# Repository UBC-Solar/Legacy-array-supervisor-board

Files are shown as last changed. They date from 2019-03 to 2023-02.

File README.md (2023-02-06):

# Array Supervisor Board

The Array Supervisor Board (ASB) was designed for Daybreak in the summer of 2019 during preparations for FSGP 2019. Unfortunately, the team couldn't get it working before the competition and scrapped it (indeed, the team did not end up bringing Daybreak to FSGP 2019 as it wasn't finished in time). The ASB was at that point deemed an unnecessary addition for Daybreak and was never troubleshooted further and installed. That said, it was a useful concept, and the concept has been pursued for UBC Solar's next car following Daybreak.

The board was designed to be capable of measuring several voltages, currents and temperatures for the solar array, as well as controlling 3 relays to individually switch the two MPPTs on and off the high voltage bus. It is based on an STM32 Nucleo board and a TLV2556 ADC.

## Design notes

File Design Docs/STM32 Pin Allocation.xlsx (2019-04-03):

CN7 | Pin Name | Main Function | Default Alternate Function | Remap Alternate Function | Feature/Notes | ASB Function | CN10 | Pin Name | Main Function | Default Alternate Function | Remap Alternate Function | Feature/Notes | ASB Function
1 | PC10 | I/O | - | USART3_TX | 5V tolerant | I_OUT_1_OCD (GPIO) | 1 | PC9 | I/O | - | TIM3_CH4 | 5V tolerant | Power On LED (GPIO)
2 | PC11 | I/O | - | USART3_RX | 5V tolerant | I_IN_1_OCD (GPIO) | 2 | PC8 | I/O | - | TIM3_CH3 | 5V tolerant | Error LED (GPIO)
3 | PC12 | I/O | - | USART3_CK | 5V tolerant | I_OUT_2_OCD (GPIO) | 3 | PB8 | I/O | TIM4_CH3 | I2C1_SCL / CANRX | 5V tolerant, not connected when SB46,SB52 off | NC
4 | PD2 | I/O | TIM3_ETR | - | 5V tolerant | I_IN_2_OCD (GPIO) | 4 | PC6 | I/O | - | TIM3_CH1 | 5V tolerant | Generic LED 1 (GPIO)
5 | VDD | Supply | - | - | - | NC | 5 | PB9 | I/O | TIM4_CH4 | I2C1_SDA / CANTX | 5V tolerant, not connected when SB46,SB52 off | NC
6 | E5V | - | - | - | External 5V supply | 5V In from Buck (POWER) | 6 | PC5 | I/O | ADC12_IN15 | - | - | Voltage Sense 1 (ADC)
7 | BOOT0 | BOOT0 | - | - | For STM Boot Up, default = 0 but can be jumper'd high | NC | 7 | AVDD | Supply | Analog Vref | - | Connected to VDD through SB57 | NC
8 | GND | GND | - | - | - | GND (POWER) | 8 | U5V | Supply | USB 5V | - | - | NC
9 | NC | - | - | - | - | NC | 9 | GND | GND | - | - | - | GND (POWER)
10 | NC | - | - | - | - | NC | 10 | NC | NC | - | - | - | NC
11 | NC | - | - | - | - | NC | 11 | PA5 | I/O | SPI1_SCK / ADC12_IN5 | - | Connected to LD2 LED on nucleo board | Ext_ADC_SCK (SPI)
12 | IOREF | 3V3 Vref | - | - | Connected to 3V3 | NC | 12 | PA12 | I/O | USART1_RTS / CANTX / USBDP / TIM1_ETR | - | 5V tolerant | CANTX (CAN)
13 | PA13 | JTMS/SWDIO (JTAG) | - | I/O | 5V tolerant | JTAG (NC) | 13 | PA6 | I/O | SPI1_MISO / ADC12_IN6 / TIM3_CH1 | TIM1_BKIN | - | Ext_ADC_MISO (SPI)
14 | RESET | NRST | - | - | Connected to B2 button on Nucleo for reseting the MCU | NC | 14 | PA11 | I/O | USART1_CTS / CANRX / USBDM / TIM1_CH4 | - | 5V tolerant | CANRX (CAN)
15 | PA14 | JTCK/SWCLK (JTAG) | - | I/O | 5V tolerant | JTAG (NC) | 15 | PA7 | I/O | SPI_MOSI / ADC12_IN7 / TIM3_CH2 | TIM1_CH1N | - | Ext_ADC_MOSI (SPI)
16 | 3V3 | External 3V3 | - | - | 3V3 output, 500mA max | 3V3 Out (POWER) | 16 | PB12 | I/O | SPI2_NSS / I2C2_SMBAI / USART3_CK / TIM1_BKIN | - | 5V tolerant | Relay Control 1 (GPIO)
17 | PA15 | JTDI (JTAG) | - | TIM2_CH1_ETR, I/O, SPI1_NSS | 5V tolerant | JTAG (NC) | 17 | PB6 | I/O | I2C1_SCL / TIM4_CH1 | USART1_TX | 5V tolerant | Ext_ADC_EOC (GPIO)
18 | 5V | External 5V | - | - | 5V output, 500mA max | 5V Out (POWER) | 18 | PB11 | I/O | I2C2_SDA / USART3_RX | TIM2_CH4 | 5V tolerant | Relay Control 2 (GPIO)
19 | GND | GND | - | - | - | GND (POWER) | 19 | PC7 | I/O | - | TIM3_CH2 | 5V tolerant | I_IN_3_OCD (GPIO)
20 | GND | GND | - | - | - | GND (POWER) | 20 | GND | GND | - | - | - | GND (POWER)
21 | PB7 | I/O | I2C1_SDA / TIM4_CH2 | USART1_RX | 5V tolerant | I_OUT_3_OCD (GPIO) | 21 | PA9 | I/O | USART1_TX / TIM1_CH2 | - | 5V tolerant | USART1_TX (NC)
22 | GND | GND | - | - | - | GND (POWER) | 22 | PB2 | PB2 / BOOT1 | - | - | 5V tolerant | Relay Control 3 (GPIO)
23 | PC13 | I/O | TAMPER-RTC (Real Time Clock) | - | Connected to B1 user button | NC | 23 | PA8 | I/O | USART1_CK / TIM1_CH1 / MCO | - | 5V tolerant | USART1_CK (NC)
24 | VIN | External VIN | - | - | Can take 7-12V | 12V In (POWER) | 24 | PB1 | I/O | ADC12_IN9 / TIM3_CH4 | TIM1_CH3N | - | Voltage Sense 2 (ADC)
25 | PC14 | I/O | OSC32_IN | - | Used for LSE (low speed external clock) | NC | 25 | PB10 | I/O | I2C2_SCL / USART3_TX | TIM2_CH3 | 5V tolerant
26 | NC | - | - | - | - | NC | 26 | PB15 | I/O | SPI2_MOSI / TIM1_CH3N | - | 5V tolerant
27 | PC15 | I/O | OSC32_OUT | - | Used for LSE (low speed external clock) | NC | 27 | PB4 | I/O | JNTRST (JTAG) | - | 5V tolerant | JTAG (NC)
28 | PA0 | I/O | WKUP / USART2_CTS / ADC12_IN0 / TIM2_CH1_ETR | - | - | NC | 28 | PB14 | I/O | SPI2_MISO / USART3_RTS / TIM1_CH2N | - | 5V tolerant
29 | PD0 | I/O | - | CANRX | 5V tolerant, used for HSE, 8MHz external clock | NC | 29 | PB5 | I/O | I2C1_SMBAI | TIM3_CH2 / SPI1_MOSI | -
30 | PA1 | I/O | USART2_RTS / ADC12_IN1 / TIM2_CH2 | - | - | Input Current Sense 1 (ADC) | 30 | PB13 | I/O | SPI2_SCK / USART3_CTS / TIM1_CH1N | - | 5V tolerant
31 | PD1 | I/O | - | CANTX | 5V tolerant, used for HSE, 8MHz external clock | NC | 31 | PB3 | JTDO (JTAG) | - | TIM2_CH2 / PB3 / TRACESWO/ SPI1_SCK | 5V tolerant | JTAG (NC)
32 | PA4 | I/O | SPI1_NSS / USART2_CK / ADC12_IN4 | - | - | Ext_ADC_NSS (SPI) | 32 | AGND | GND | Analog Ground | - | Connected to GND through SB60 | GND (POWER)
33 | VBAT | Supply, 3.3V | - | - | Backup supply for RTC and backup registers | NC | 33 | PA10 | I/O | USART1_RX / TIM1_CH3 | - | 5V tolerant | USART1_RX (NC)
34 | PB0 | I/O | ADC12_IN8 / TIM3_CH3 | TIM1_CH2N | - | Input Current Sense 2 (ADC) | 34 | PC4 | I/O | ADC12_IN14 | - | - | Voltage Sense 3 (ADC)
35 | PC2 | I/O | ADC12_IN12 | - | - | Output Current Sense 1 (ADC) | 35 | PA2 | I/O | USART2_TX / ADC12_IN2 / TIM2_CH3 | - | Used for ST-LINK MCU | NC
36 | PC1 | I/O | ADC12_IN11 | - | - | Input Current Sense 3 (ADC) | 36 | NC | NC | - | - | - | NC
37 | PC3 | I/O | ADC12_IN13 | - | - | Output Current Sense 2 (ADC) | 37 | PA3 | I/O | USART2_RX / ADC12_IN3 / TIM2_CH4 | - | Used for ST-LINK MCU | NC
38 | PC0 | I/O | ADC12_IN10 | - | - | Output Current Sense 3 (ADC) | 38 | NC | NC | - | - | - | NC

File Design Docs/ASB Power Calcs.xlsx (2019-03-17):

12V Supply | Max Current Draw (mA) | 3.3V Supply | Max Current Draw (mA) | 5V Supply | Max Current Draw (mA)
STM MCU | 250 | Current Sensor x 6 | 150 | CAN Transceiver
Voltage Sense Op Amp x 3 | 12 | External ADC | 2.5
Temperature Sensor x 12 | 1
Gigavac contactor | 170
Omron Relay x 2 | 200

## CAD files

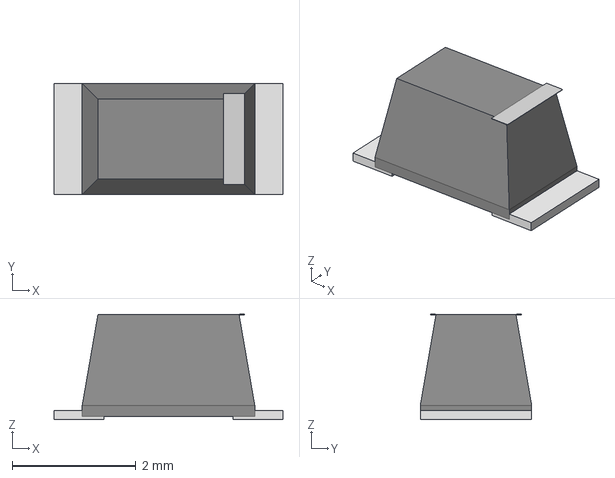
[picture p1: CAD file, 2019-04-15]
3D Models/CGRKM.step
3.71 x 1.80 x 1.71 mm

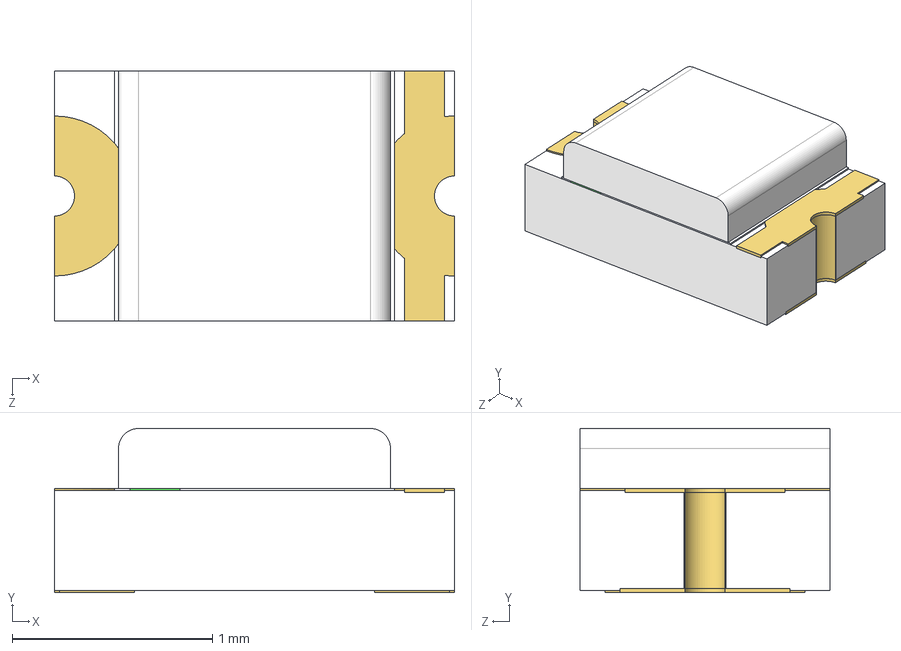
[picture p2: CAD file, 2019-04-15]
3D Models/L0805.step
2.00 x 0.82 x 1.25 mm

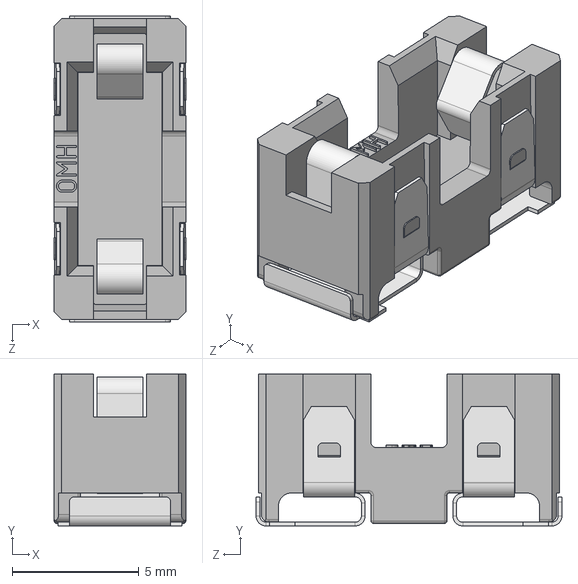
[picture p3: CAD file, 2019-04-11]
3D Models/FUSE HLDR CARTRIDGE 125V 5A SMD.STEP
5.20 x 6.00 x 12.1 mm

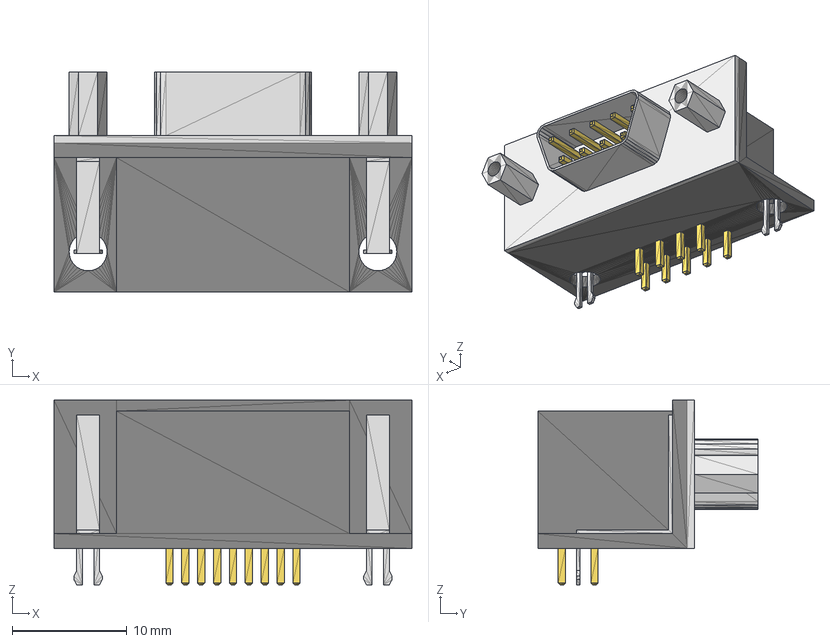
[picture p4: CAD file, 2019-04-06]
3D Models/D9 Connector.step
31.2 x 19.2 x 16.1 mm

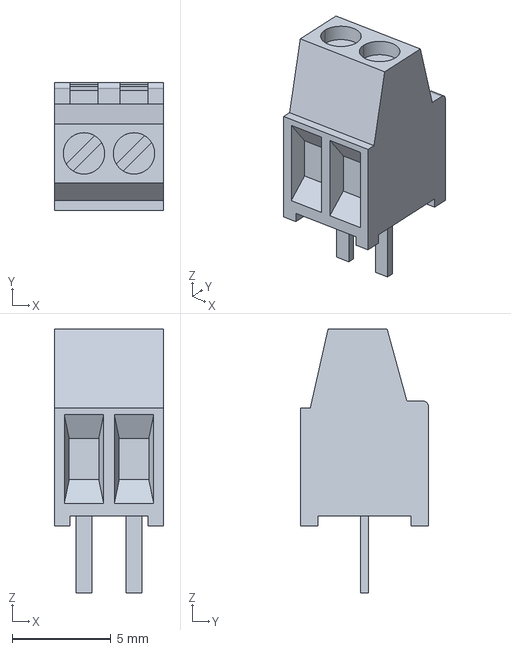
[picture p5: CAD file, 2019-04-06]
3D Models/TD Connectivity 28234-2.stp
5.54 x 6.50 x 13.4 mm

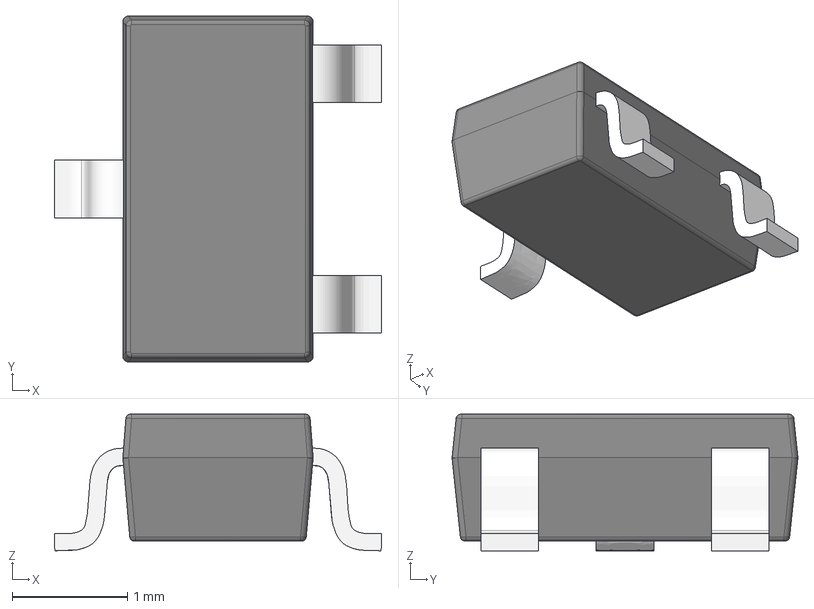
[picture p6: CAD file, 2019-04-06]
3D Models/MOSFET DMG6968U SOT23-3.stp
2.84 x 3.00 x 1.18 mm

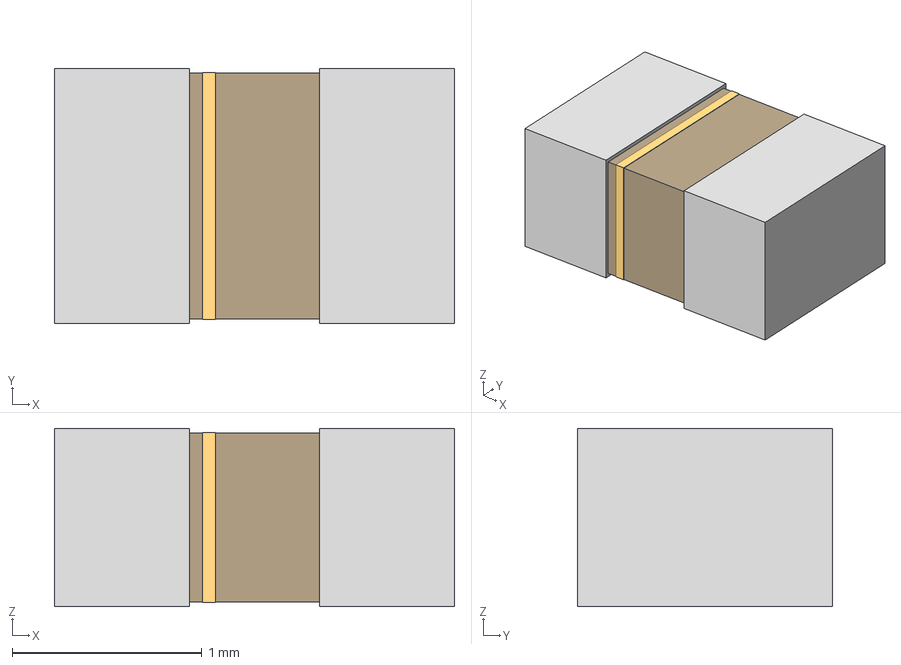
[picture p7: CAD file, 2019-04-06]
3D Models/CAP_0805C-L.step
2.11 x 1.35 x 0.94 mm

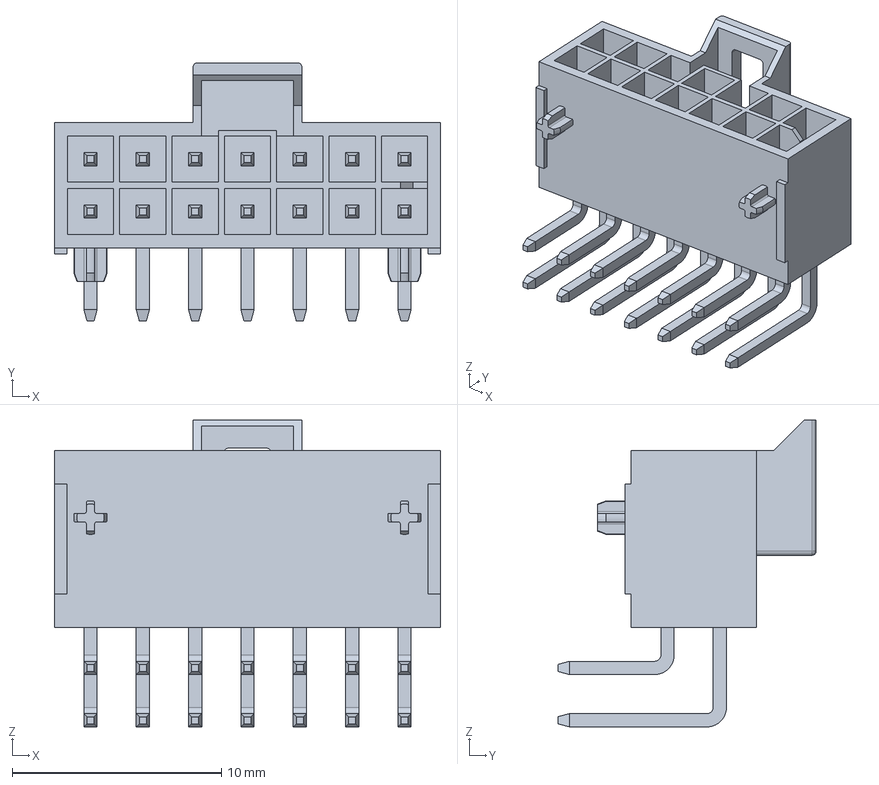
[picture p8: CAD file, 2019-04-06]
3D Models/MOLEX 105314 11 14 CON.stp
18.4 x 12.3 x 14.7 mm

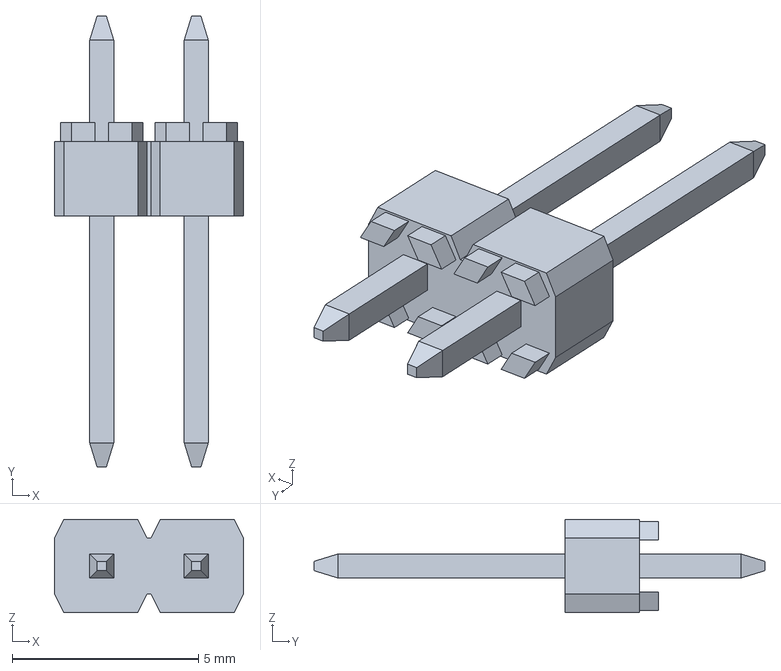
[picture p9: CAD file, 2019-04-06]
3D Models/Molex 901200762.stp
5.08 x 12.1 x 2.50 mm

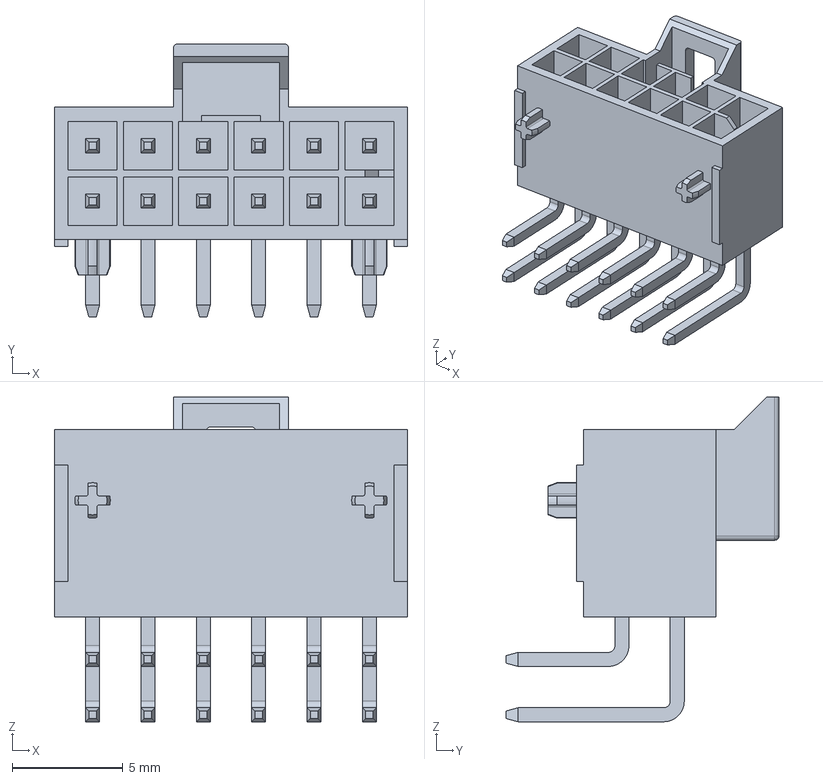
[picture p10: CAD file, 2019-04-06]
3D Models/MOLEX 105314 11 12 CON.stp
15.9 x 12.3 x 14.7 mm

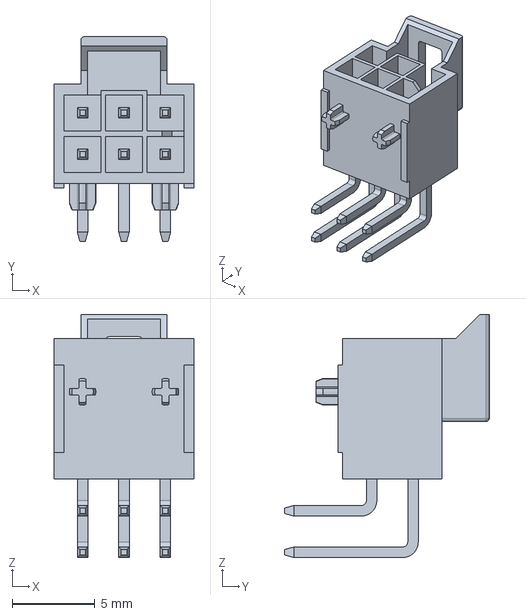
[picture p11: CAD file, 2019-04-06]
3D Models/MOLEX 105314 11 06 CON.stp
8.44 x 12.3 x 14.7 mm

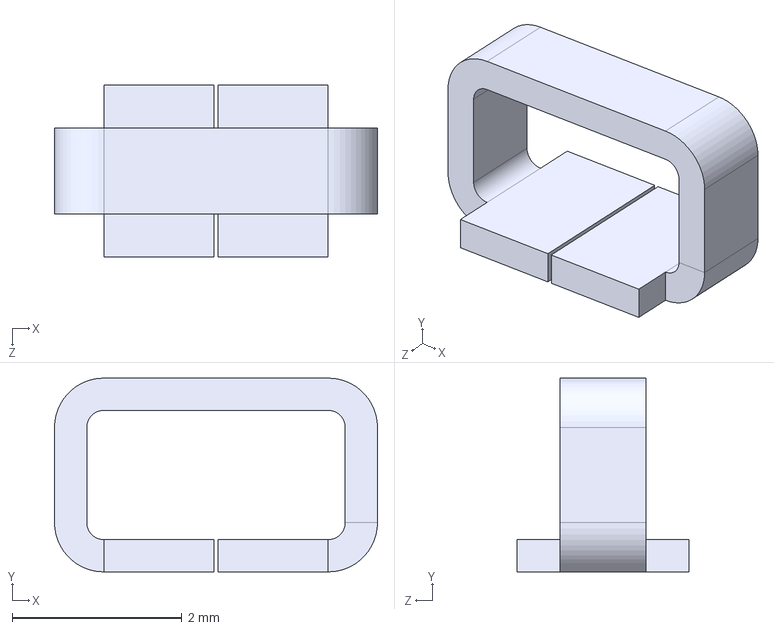
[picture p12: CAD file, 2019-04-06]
3D Models/5019 KEYSTONE SMT TEST POINT.STEP
3.81 x 2.29 x 2.03 mm

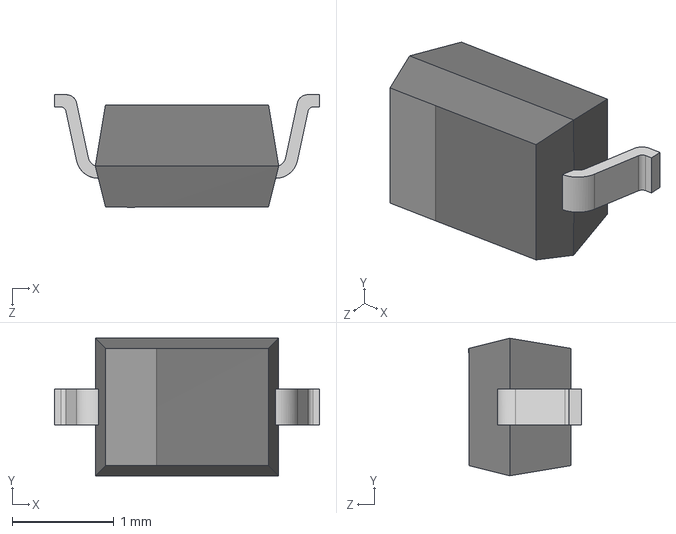
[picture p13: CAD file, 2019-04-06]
3D Models/SOD-323.STEP
2.60 x 1.35 x 1.10 mm

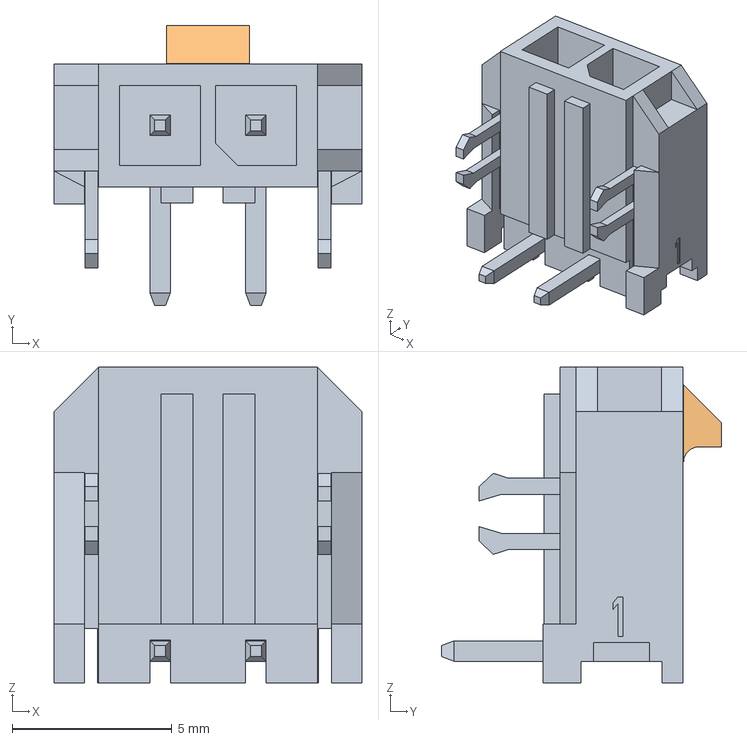
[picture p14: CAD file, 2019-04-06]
3D Models/Right Angle Header 436500205.stp
9.65 x 8.79 x 9.90 mm

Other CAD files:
3D Models/CAP_0805C-M.step
3D Models/C0805.step
3D Models/ESQ-119-24-T-D.stp
3D Models/SOIC08 narrow.stp
3D Models/1053141106.stp
3D Models/1053141208.stp
3D Models/705530001.stp
3D Models/901200763.stp
3D Models/CAPC-0805-T0.95-BN.stp
3D Models/CAPC-0805-T1.35-BN.stp
3D Models/RESC-0805.stp

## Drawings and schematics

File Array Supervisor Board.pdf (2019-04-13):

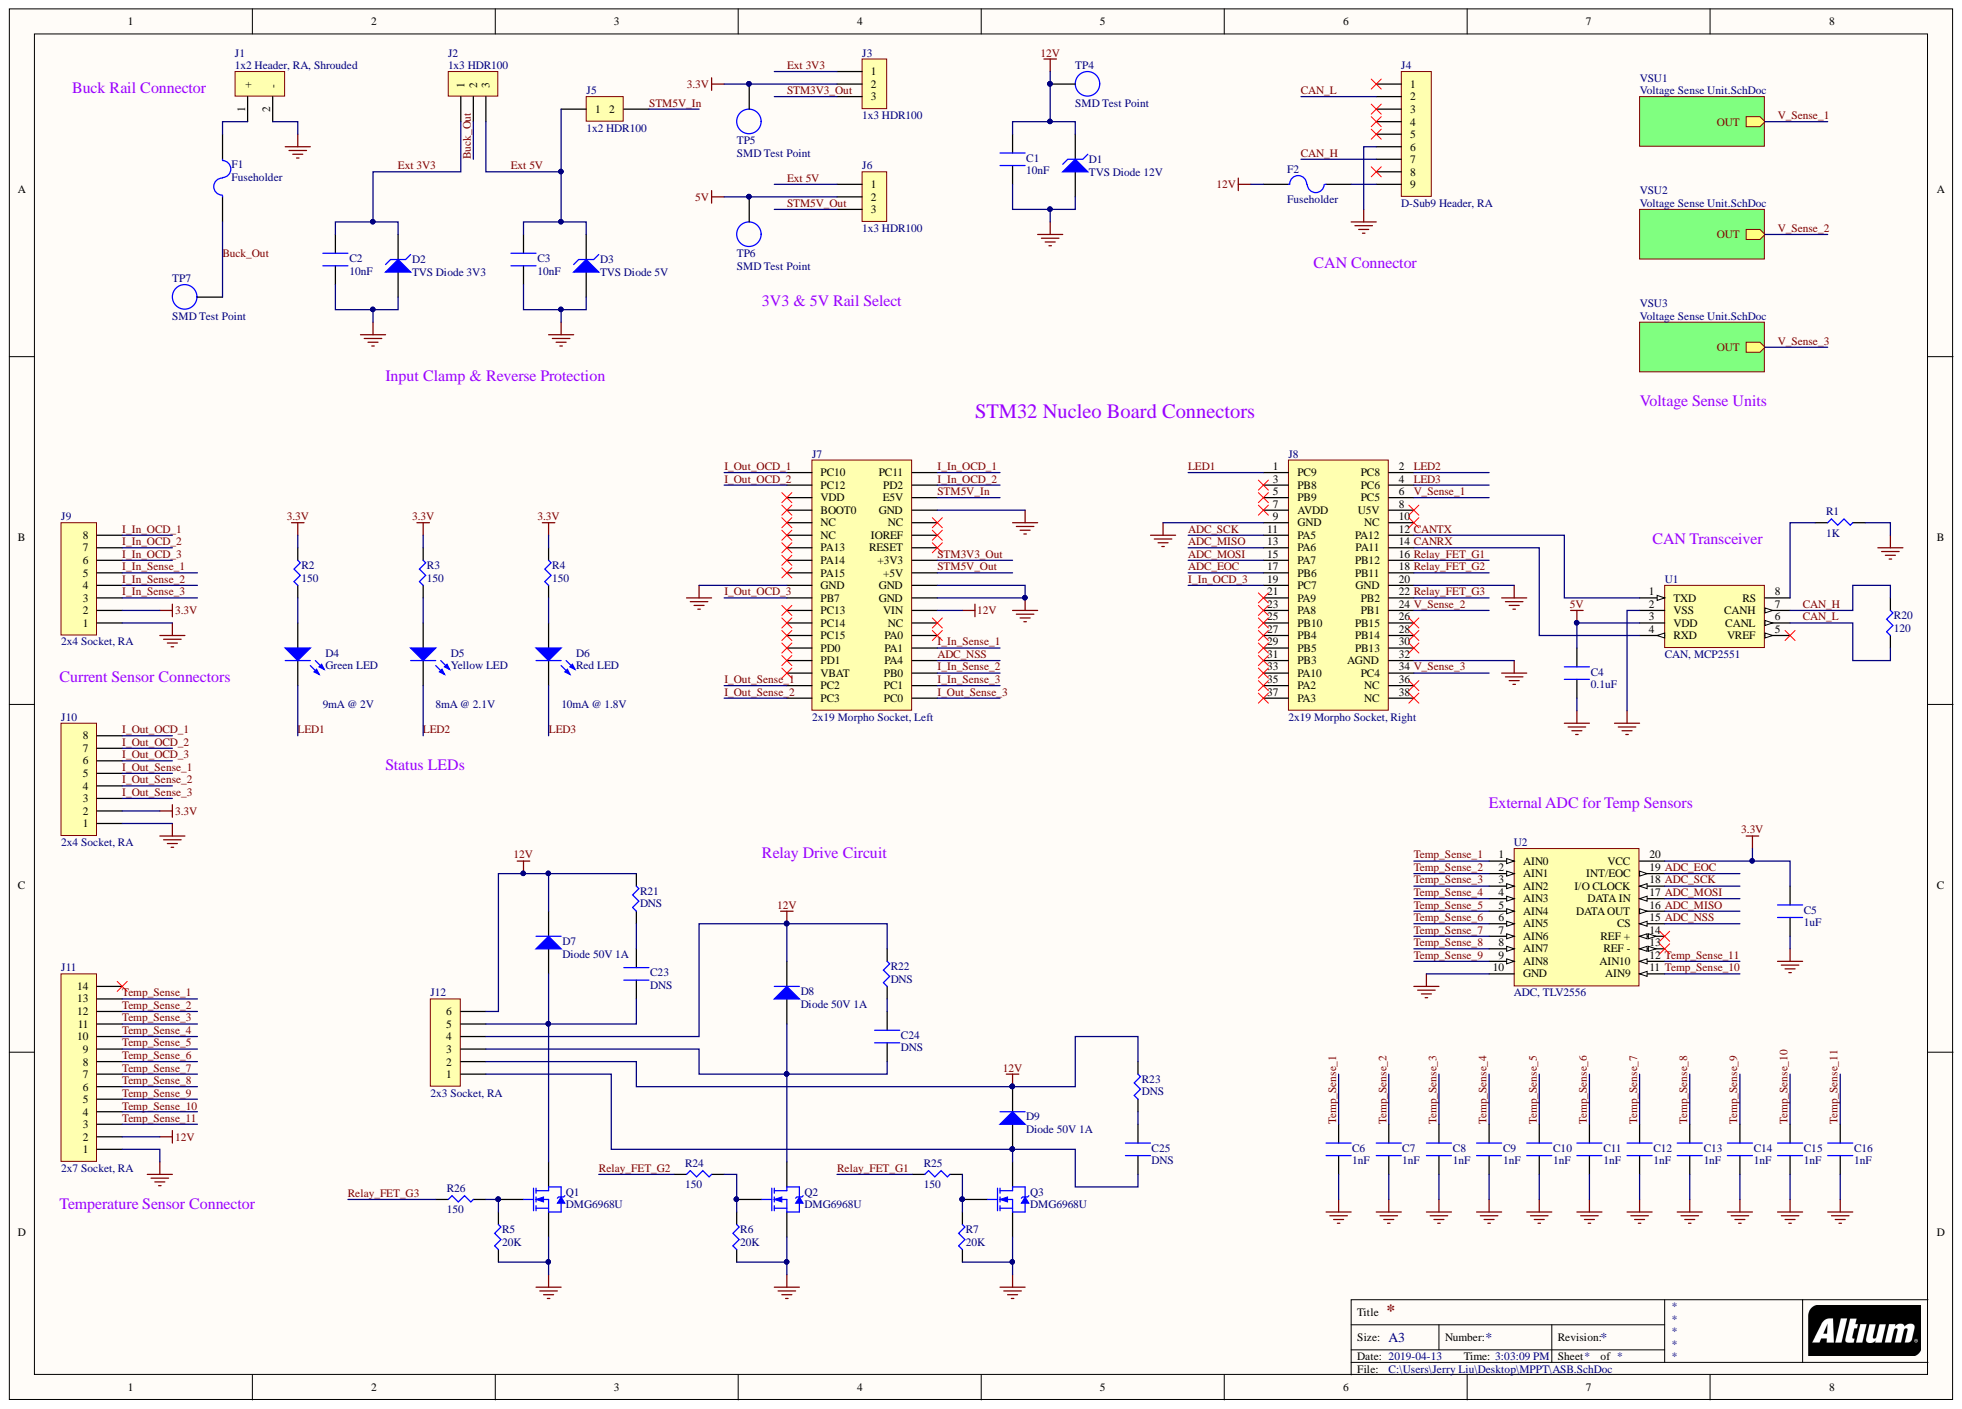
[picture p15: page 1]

VSU1
Voltage Sense Unit.SchDoc

VSU2

VSU3

Input Clamp & Reverse Protection

External ADC for Temp Sensors

* Title | * * * * *

Size: A3 | Number: * | Revision: *
Date: 2019-04-13 Time: 3:03:09 PM | | Sheet * of *

C:\Users\Jerry Liu\Desktop\MPPT\ASB.SchDoc

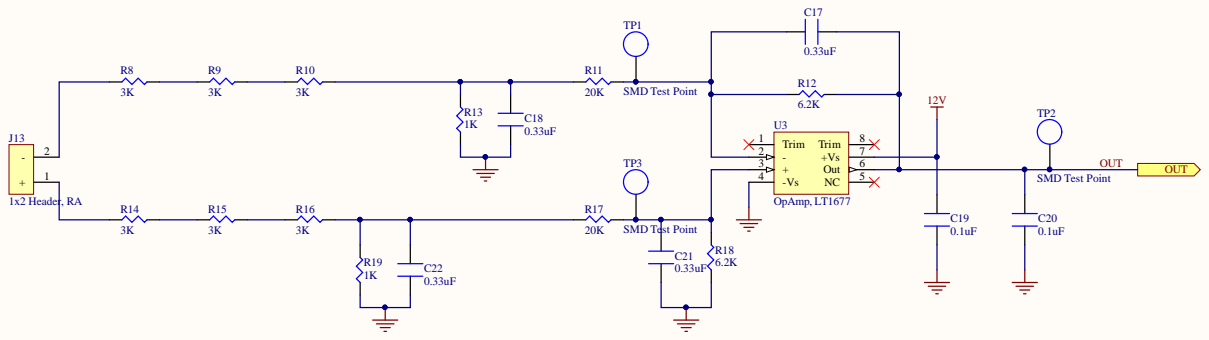
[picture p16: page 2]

* Title | * * * * *

Size: A3 | Number: * | Revision: *
Date: 2019-04-13 Time: 3:03:09 PM | | Sheet * of *

C:\Users\Jerry Liu\Desktop\MPPT\Voltage Sense Unit\Voltage Sense Unit.SchDoc

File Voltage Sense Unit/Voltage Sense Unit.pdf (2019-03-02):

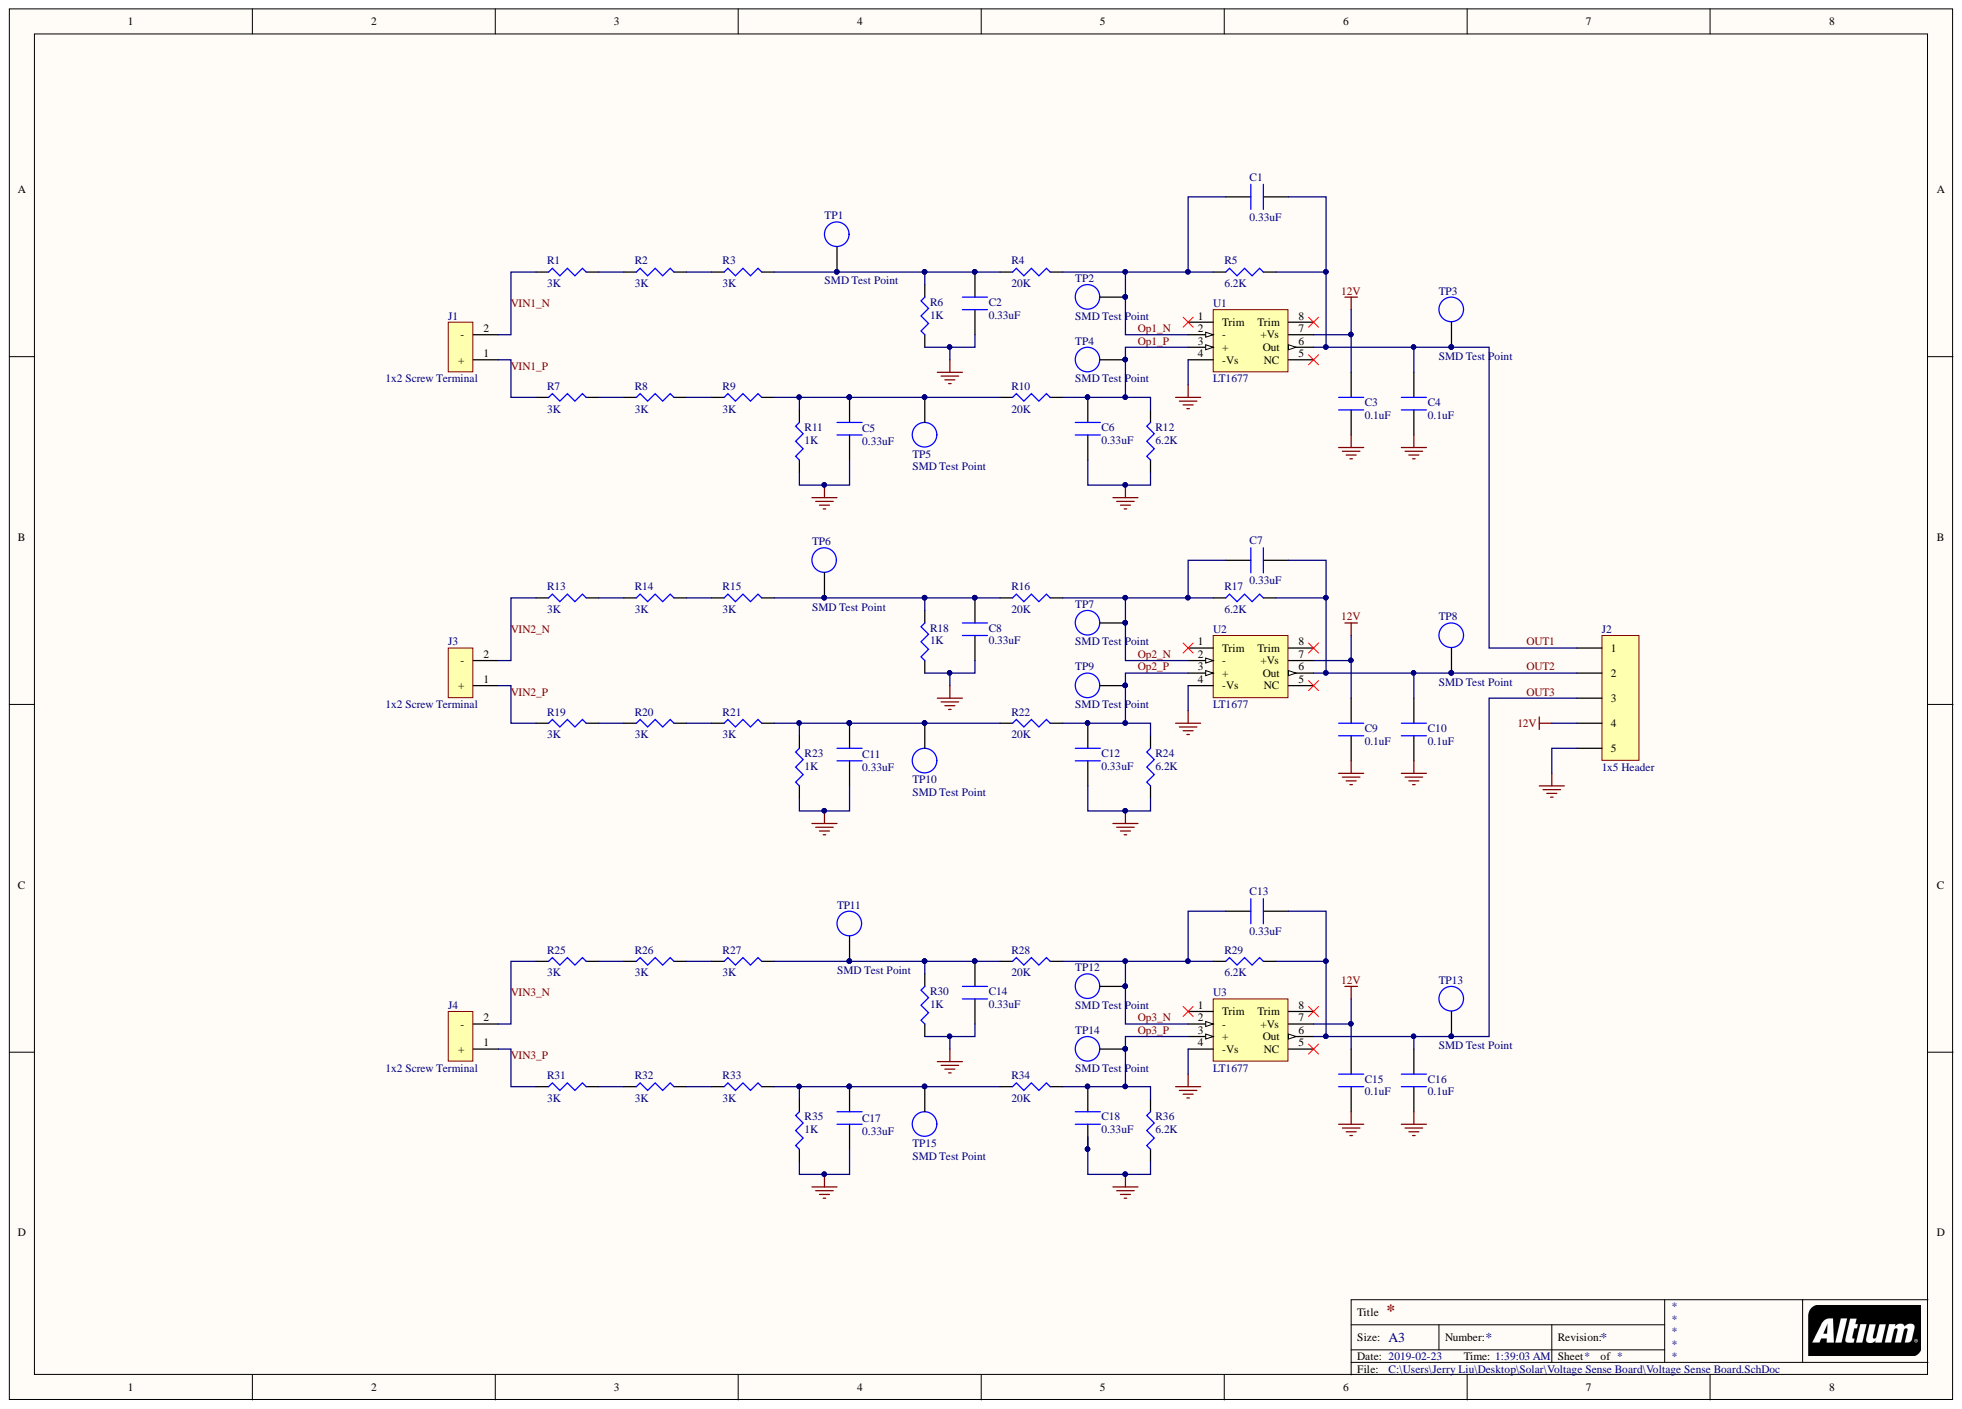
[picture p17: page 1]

4 | C | 5 | SM D Tes t Point C 4 0.1uF TP8 O U T 1

Size: A 3 | Number : * | Revi s ion: *
Date: 2019-02-23 Ti me: 1:39:03 A M | | Sheet * of *

tage Sense Board.SchDoc

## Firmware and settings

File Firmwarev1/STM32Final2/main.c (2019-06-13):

#include "ADC_config.h"
#include "SPI_config.h"
#include "utils.h"
#include "CAN.h"

#define TEMPERATURE_CONVERSION 0x01
#define CURRENT_CONVERSION 0x01
#define VOLTAGE_CONVERSION 0x01
#define TEMPERATURE_THRESHOLD 0xF000
#define CURRENT_THRESHOLD 0xF000
#define VOLTAGE_THRESHOLD 0xF000

CAN_msg_t CAN_rx_msg;
CAN_msg_t CAN_tx_msg;
static uint8_t CAN_Interrupt_Flag = 0;	 // will eventually be a timer 

int main(void) {
	//CANInit();
	uint16_t temperatures[NUMBER_OF_SPI_ADC_CHANNELS]; 
	uint16_t currents[NUMBER_OF_CURRENT_ADC_CHANNELS];
	uint16_t voltages[NUMBER_OF_VOLTAGE_ADC_CHANNELS];
	uint8_t i;
	uint16_t temperature_error, current_error, voltage_error;

	PeripheralInit_SPI1();
	PeripheralInit_ADC1();
	PeripheralInit_GPIO();
	while (1) {
		// gets readings
		Get_Temperature_Readings(temperatures); 
		Get_Current_Voltage_Readings(currents, voltages);
		temperature_error = 0;
		current_error = 0;
		voltage_error = 0;
		
		// processes readings and checks if they exceed thresholds
		for (i = 0; i < NUMBER_OF_SPI_ADC_CHANNELS; i++) {
			temperatures[i] = TEMPERATURE_CONVERSION * (temperatures[i] >> 4);
			if (temperatures[i] > TEMPERATURE_THRESHOLD) {
				temperature_error |= 1 << i;
			}
		}
		for (i = 0; i < NUMBER_OF_CURRENT_ADC_CHANNELS; i++) {
			currents[i] = CURRENT_CONVERSION * currents[i];
			if (currents[i] > CURRENT_THRESHOLD) {
				current_error |= 1 << i;
			}
		}
		for (i = 0; i < NUMBER_OF_VOLTAGE_ADC_CHANNELS; i++) {
			voltages[i] = VOLTAGE_CONVERSION * voltages[i];
			if (voltages[i] > VOLTAGE_THRESHOLD) {
				voltage_error |= 1 << i;
			}
		}
		
		uint8_t ocd = Check_OCD();
		if (ocd) { // if we hit OCD limits, warn the MCN and shutdown
			Set_Contactors(1);
			CAN_msg_t current_error_message = {CRITICAL_OCD_ERROR_ID, {ocd}, 1};
			//CANSend(&current_error_message);
			break;
		}
		Set_LEDS(temperature_error, current_error, voltage_error); 
		if (current_error | voltage_error) { // if we encounter a critical error that may damage components, warn the MCN and shutdown
			Set_Contactors(1);
			uint8_t currhi = current_error >> 8;
			uint8_t currlo = current_error & 0xFF;
			uint8_t volthi = voltage_error >> 8;
			uint8_t voltlo = voltage_error & 0xFF;
			CAN_msg_t critical_error_message = {CRITICAL_ERROR_ID, {currlo, currhi, voltlo, volthi}, 4};
			//CANSend(&critical_error_message);
			break;
		}
		if (temperature_error) { //      if panel begins to overheat, warn the MCN
			uint8_t hi = temperature_error >> 8;
			uint8_t lo = temperature_error & 0xFF;
			CAN_msg_t noncritical_error_message = {NON_CRITICAL_ERROR_ID, {lo, hi}, 2};
			//CANSend(&noncritical_error_message);
		}
		
		if (CAN_Interrupt_Flag) { // interrupt sets this flag, which triggers a data send
			CAN_Interrupt_Flag = 0;
			Send_CAN_Data(temperatures, currents, voltages);
		}
	}
}

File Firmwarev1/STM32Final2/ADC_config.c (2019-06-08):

#include "ADC_config.h"

const uint16_t ADC_Channels[NUMBER_OF_ADC_CHANNELS] = {ADC_Channel_15, ADC_Channel_9, ADC_Channel_14, ADC_Channel_1, ADC_Channel_8, ADC_Channel_11, ADC_Channel_12, ADC_Channel_13, ADC_Channel_10};
const uint16_t ADC_Mapping[NUMBER_OF_ADC_CHANNELS] = {VOLTAGE, VOLTAGE, VOLTAGE, CURRENT, CURRENT, CURRENT, CURRENT, CURRENT, CURRENT};
const uint16_t Voltage_Channels[NUMBER_OF_VOLTAGE_ADC_CHANNELS] = {ADC_Channel_15, ADC_Channel_9, ADC_Channel_14};
const uint16_t Current_Channels[NUMBER_OF_CURRENT_ADC_CHANNELS] = {ADC_Channel_1, ADC_Channel_8, ADC_Channel_11, ADC_Channel_12, ADC_Channel_13, ADC_Channel_10};

/*
Measures values of current and voltage sensors and writes them to
appropriate arrays
*/
void Get_Current_Voltage_Readings(uint16_t * currents, uint16_t * voltages) {
	uint16_t value;
	uint8_t voltage_counter = 0;
	uint8_t current_counter = 0;
	for (uint8_t i = 0; i < NUMBER_OF_ADC_CHANNELS; i++) {
		value = Get_ADC_Converted_Value(ADC_Channels[i]);
		if (ADC_Mapping[i] == VOLTAGE) {
			voltages[voltage_counter] = value;
			voltage_counter++;
		} else if (ADC_Mapping[i] == CURRENT) {
			currents[current_counter] = value;
			current_counter++;
		}
	}
}

/*
Gets the value converted from a single ADC channel
Parameters: Channel to read from
Returns: 12-bit value read from ADC 
*/
uint16_t Get_ADC_Converted_Value(uint8_t channel) {
	ADC_RegularChannelConfig(ADC1, channel, 1, ADC_SampleTime_7Cycles5);
	ADC_SoftwareStartConvCmd(ADC1, ENABLE);
	while (!ADC_GetFlagStatus(ADC1, ADC_FLAG_EOC));
	return ADC_GetConversionValue(ADC1);
}

/*
Configures ADC channels for use
*/
void Configure_ADC_Channels(void) {
	// Configure all channels with sample time, channel, rank
	for (uint8_t i = 0; i < NUMBER_OF_ADC_CHANNELS; i++) {
		ADC_RegularChannelConfig(ADC1, ADC_Channels[i], i + 1, ADC_SampleTime_7Cycles5);
	}
}

/*
Initializes ADC peripherals
*/
void PeripheralInit_ADC1(void) {
	ADC_DeInit(ADC1); //deinitialize to reconfigure
	ADC_InitTypeDef ADC_InitStruct;
	// Enable RCC clk
	RCC_APB2PeriphClockCmd(RCC_APB2Periph_ADC1,ENABLE);
	// Right align data
	ADC_InitStruct.ADC_DataAlign = ADC_DataAlign_Right;
	ADC_InitStruct.ADC_Mode = ADC_Mode_Independent;
	// keep scanning 
	ADC_InitStruct.ADC_ScanConvMode = ENABLE;
	// continuous
	ADC_InitStruct.ADC_ContinuousConvMode = ENABLE; 
	ADC_InitStruct.ADC_NbrOfChannel = NUMBER_OF_ADC_CHANNELS;
	// no external trigger
	ADC_InitStruct.ADC_ExternalTrigConv = ADC_ExternalTrigConv_None;
	ADC_Init(ADC1, &ADC_InitStruct);
	Configure_ADC_Channels();
	ADC_Cmd(ADC1, ENABLE);
	//ADC_DMACmd(ADC1, ENABLE);
	// Calibrate ADC
	ADC_ResetCalibration(ADC1);
	while(ADC_GetResetCalibrationStatus(ADC1));
	ADC_StartCalibration(ADC1);
	while (ADC_GetCalibrationStatus(ADC1) == SET);
	
	//Set up GPIO pins as AIN
	GPIO_InitTypeDef GPIO_InitStruct;
	RCC_APB2PeriphClockCmd(RCC_APB2Periph_GPIOA | RCC_APB2Periph_GPIOB | RCC_APB2Periph_GPIOC, ENABLE);
	
	GPIO_StructInit(&GPIO_InitStruct);
	GPIO_InitStruct.GPIO_Pin = GPIO_Pin_1;
  GPIO_InitStruct.GPIO_Mode = GPIO_Mode_AIN;
	GPIO_Init(GPIOA, &GPIO_InitStruct);
	
	GPIO_StructInit(&GPIO_InitStruct);
	GPIO_InitStruct.GPIO_Pin = GPIO_Pin_0 | GPIO_Pin_1;
  GPIO_InitStruct.GPIO_Mode = GPIO_Mode_AIN;
	GPIO_Init(GPIOB, &GPIO_InitStruct);
	
	GPIO_StructInit(&GPIO_InitStruct);
	GPIO_InitStruct.GPIO_Pin = GPIO_Pin_0 | GPIO_Pin_1 | GPIO_Pin_2 | GPIO_Pin_3 | GPIO_Pin_4 | GPIO_Pin_5;
  GPIO_InitStruct.GPIO_Mode = GPIO_Mode_AIN;
	GPIO_Init(GPIOC, &GPIO_InitStruct);
}

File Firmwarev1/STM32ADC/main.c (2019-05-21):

#include "stm32f10x.h"
#include "stm32f10x_gpio.h"
#include "stm32f10x_rcc.h"

void PeripheralInit_ADC_GPIO(void);
void PeripheralInit_ADC(void);
int Get_ADC_Converted_Value(uint8_t channel);
double Get_Voltage(uint8_t channel); // need to implement this: does stm32 not use IEEE floating point?

int main(void) {
	PeripheralInit_ADC_GPIO();
	PeripheralInit_ADC();
	int ADCValue = Get_ADC_Converted_Value(ADC_Channel_0);
	return 0;
}

int Get_ADC_Converted_Value(uint8_t channel) {
	ADC_RegularChannelConfig(ADC1, channel, 1, ADC_SampleTime_7Cycles5);
	ADC_SoftwareStartConvCmd(ADC1, ENABLE);
	while (!ADC_GetFlagStatus(ADC1, ADC_FLAG_EOC));
	return ADC_GetConversionValue(ADC1);
}

void PeripheralInit_ADC(void) {
	ADC_DeInit(ADC1); //deinitialize to reconfigure
	ADC_InitTypeDef ADC_InitStruct;
	RCC_APB2PeriphClockCmd(RCC_APB2Periph_ADC1,ENABLE);
	ADC_InitStruct.ADC_DataAlign = ADC_DataAlign_Right;
	ADC_InitStruct.ADC_Mode = ADC_Mode_Independent;
	ADC_InitStruct.ADC_ScanConvMode = DISABLE;
	ADC_InitStruct.ADC_NbrOfChannel = ADC_Channel_0;
	ADC_InitStruct.ADC_ExternalTrigConv = ADC_ExternalTrigConv_None;
	ADC_Init(ADC1, &ADC_InitStruct);
	ADC_Cmd(ADC1, ENABLE);
	ADC_StartCalibration(ADC1);
	while (ADC_GetCalibrationStatus(ADC1) == SET);
}

void PeripheralInit_ADC_GPIO(void) {
	GPIO_InitTypeDef GPIO_InitStruct;
	RCC_APB2PeriphClockCmd(RCC_APB2Periph_GPIOA | RCC_APB2Periph_GPIOB | RCC_APB2Periph_GPIOC, ENABLE);
	
	GPIO_StructInit(&GPIO_InitStruct);
	//setup appropriate pins
	GPIO_InitStruct.GPIO_Pin = GPIO_Pin_0;
  GPIO_InitStruct.GPIO_Mode = GPIO_Mode_AIN;
  GPIO_InitStruct.GPIO_Speed = GPIO_Speed_50MHz;
	GPIO_Init(GPIOA, &GPIO_InitStruct);
}

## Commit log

2019-03-02 initial voltage sense PCB files
    [CAPC-0805-T1.35-BN.stp, MPPT0.PrjPcb, PCB1.PcbDoc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]
2019-03-16 Restructured Repo (merge voltage sense board with ASB using hierarchical design)
    [ASB Power Calcs.xlsx, ASB.SchDoc, ASB.SchLib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]
2019-03-17 moved some auto generated files to gitignore, added design docs
    [ASB Power Calcs.xlsx, ASB.PcbLib, ASB.SchDoc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]
2019-03-21 added more parts, moved unused parts in separate library
    [ASB.PcbLib, ASB.SchDoc, ASB.SchLib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]
2019-03-21 Update Voltage Sense Unit.SchDocPreview
2019-03-22 Added more parts to schematic, added external resistor&capacitor libraries
    [ASB.SchDoc, ASB.SchLib, Array Supervisor Board.PrjPcb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]
2019-03-22 Created reading material folder
2019-03-23 Merged everything into ASB library, changed VSU into single module sheet
    [ASB.SchDoc, ASB.SchLib, Array Supervisor Board.PrjPcb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]
2019-03-23 Completed STM32 Pin Allocation, pending review
    [STM32 Pin Allocation.xlsx]
2019-04-03 updated pin allocation (added current sense OCD pins), worked on schematic
    [ASB.SchDoc, ASB.SchLib, STM32 Pin Allocation.xlsx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]
2019-04-03 added TVS diodes, optimized pin allocation, finished STM schematic connections
    [ASB.SchDoc, ASB.SchLib, STM32 Pin Allocation.xlsx]
2019-04-06 added footprints from stephen
    [ASB.PcbLib]
2019-04-06 added footprints from Anthony
    [436500205.stp, ASB.PcbLib, ESQ-119-24-T-D.stp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]
2019-04-06 added designator
    [ASB.PcbLib]
2019-04-06 Commiting PCBLIB and 3d Models
    [1053141106.stp, 5019 KEYSTONE SMT TEST POINT.STEP, ASB.PcbLib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]
2019-04-07 Added designators and outlines onto mech 5 layer
    [ASB.PcbLib]
2019-04-08 finished schematic first draft
    [ASB.SchDoc, ASB.SchLib, Array Supervisor Board.PrjPcb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]
2019-04-11 added fuse holder footprint
    [ASB.PcbLib, FUSE HLDR CARTRIDGE 125V 5A SMD.STEP]
2019-04-13 added molex header footprint
    [705530001.stp, ASB.PcbLib, ASB.SchLib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]
2019-04-13 finished schematic rev2, linked most schematic parts with footprints
    [ASB.PcbLib, ASB.SchDoc, ASB.SchLib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]
2019-04-13 created ASB.PcbDoc, starting pcb layout
    [ASB.PcbDoc, Array Supervisor Board.PrjPcb]
2019-04-15 added 4 footprints
    [1053141208.stp, 901200763.stp, ASB.PcbLib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]
2019-04-19 Update ASB.PcbLib
    STM32 Nucleo 64 pads added to pcblib
    [ASB.PcbLib]
2019-04-20 added connector to control STM board VIN
    [ASB.PcbDoc, ASB.SchDoc, Array Supervisor Board.PrjPcb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]
2019-04-20 STM32 footprint connected
    [ASB.PcbLib, ASB.SchDoc, ASB.SchLib]
2019-04-20 created PCB doc, added some design rules
    [ASB.PcbDoc, Array Supervisor Board.PrjPcb]
2019-04-20 tentatively changed board size to 200x150mm
    [ASB.PcbDoc]
2019-04-20 updated design rules, changed power plane
    [ASB.PcbDoc]
2019-04-21 changed design rules, minor schematic changes, finished layout for relay module
    [ASB.PcbLib, ASB.SchDoc]
2019-04-21 fixed 2x4 connector footprint
    [ASB.PcbLib, ASB.SchDoc, Voltage Sense Unit.SchDoc]
2019-04-21 5V rail layout work in progress
2019-04-22 added power status LEDs to schematic, created DNS variant, finished power rails layout
    [ASB.SchDoc, ASB.SchLib, Array Supervisor Board.PrjPcb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]
2019-04-25 finished layout for everything except VSUs
    [ASB.PcbLib, ASB.SchDoc]
2019-04-25 First Draft of VSU layout with board
    Requires some error checking.
2019-04-25 Fixed Right Angle Header pad designators
    [ASB.PcbLib]
2019-04-26 adjusted footprint mechanical layers
    [ASB.PcbLib]
2019-04-26 changed board dimensions, moved connectors next to the edge, added mounting holes
2019-04-26 updated mechanical assembly layer
    [ASB.PcbLib]
2019-04-26 updated a few footprints
    [ASB.PcbLib]
2019-04-27 updated mechanical layers
    [ASB.PcbLib, Array Supervisor Board.PrjPcb]
2019-04-27 Update ASB.PcbDoc
    Spread out VSUS
2019-04-27 Update ASB.PcbDoc
    text change test
2019-04-27 Update ASB.PcbDoc
    test change test 2
2019-04-27 updated footprint assembly layer
    [ASB.PcbLib]
2019-04-27 updated assembly layer on pcb
    [ASB.PcbLib]
2019-04-27 added drill table
2019-04-30 Draft of ASB layout. Mounting holes fixed, VSU's spread out as much as possible.
    [ASB.PcbLib]
2019-04-30 Added ASB CAM and 3D CAM Fixed rooms in ASB.pcb
    [ASB.GBL, ASB.GBO, ASB.GBP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]
2019-05-08 added gerber/drill files
    [ASB.DRL, ASB.GBL, ASB.GBO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]
2019-05-30 created scaled svg files of solder paste layers for laser cutting stencil
2019-06-08 Ready to test: fixed issues with CAN + OCD + LED
    [ADC_config.c, ADC_config.h, CAN.c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]
2019-06-12 updated timer configs
